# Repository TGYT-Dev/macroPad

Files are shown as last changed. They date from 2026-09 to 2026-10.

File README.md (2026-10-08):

# Images

<p align="left">
  MacroPad Foot
  MacroPad PCB<br>
  MacroPad Schem
  MacroPad Case / Assembly
</p>

# Bill of Materials
This should all be iuncluded in the macropad kit.

> 5x Cherry MX Switches
> 
> 1x Alps EC11E Rotary Encoder
> 
> 1x Seeeduino XIAO
> 
> 1x 0.91" 128x32 OLED Display
> 
> 4x M3 screws

# Notes

This is my first hardware project and I hope It turns out well... ~waiting for a review and working on minor improvements in the meantime.~

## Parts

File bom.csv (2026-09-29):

Id | Designator | Footprint | Quantity | Designation | Supplier and ref
1 | SW1, SW2, SW3, SW4, SW5 | SW_Cherry_MX_1.00u_PCB | 5 | SW_Push
2 | SW6 | RotaryEncoder_Alps_EC11E-Switch_Vertical_H20mm | 1 | RotaryEncoder_Switch
3 | U1 | XIAO-Generic-Hybrid-14P-2.54-21X17.8MM | 1 | MOUDLE-SEEEDUINO-XIAO
4 | U2 | SSD1306-0.91-OLED-4pin-128x32 | 1 | ER_OLEDM0.91_1x-I2C

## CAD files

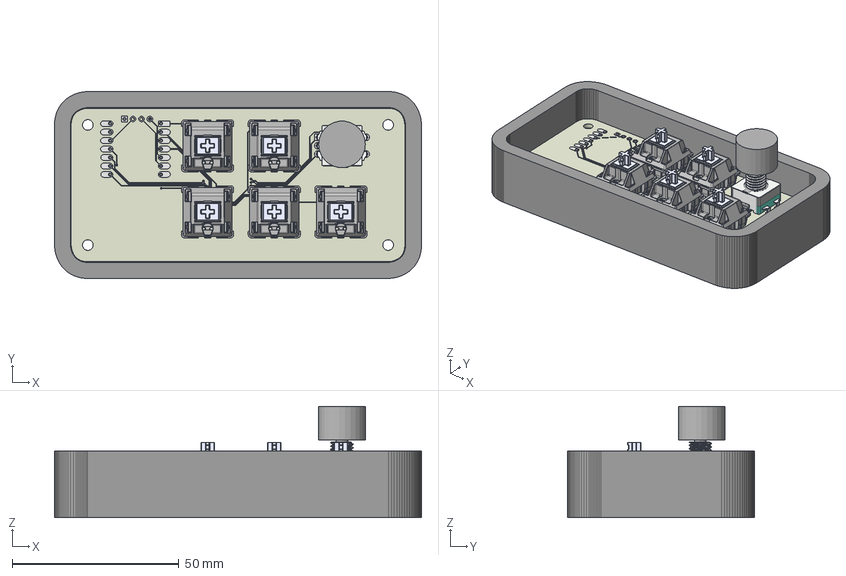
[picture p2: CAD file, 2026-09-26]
cad/MacroPad.step
110.0 x 56.0 x 33.3 mm
Case
Rotary Encoder Knob
BOSS-EXTRUDE14_6_
macroPad-unsaved-export-03wzKc_pad x 105
CUT-EXTRUDE5
Õë½Å___Ä¬ÈÏ__¨¨ _:1__Body1
macroPad-unsaved-export-03wzKc_copper x 26
Ñ½×ªÂ±áƒ«Ç· x 6
Õë½Å___Ä¬ÈÏ__¨¨ _:1__Body1_3
BOSS-EXTRUDE14_3_
U.FL Connector v1 x 3
macroPad-unsaved-export-03wzKc_PCB
BOSS-EXTRUDE7_2_
MX Ã–Ã¡ Â°Â´Â¼Ã¼ Â¡Ã¤_Â¨Â¹___Â¡Â§1:1__B ody1_4
MXÖá ÖáÌå µ×²¿ ¦Ì¡ Á2__Ä¬ÈÏ_¨¢2____¨¨_:1__Body1_3
Button (1)
macroPad-unsaved-export-03wzKc_via x 8
MX Ã–Ã¡ Â°Â´Â¼Ã¼ Â¡Ã¤_Â¨Â¹___Â¡Â§1:1__B ody1_3
MX Ã–Ã¡ Ã–Ã¡ÃŒÃ¥Â¨Â¢Â¨Â¬_ Â¡Â§Â¡Ã©Â¡Â§__:1__Body 1_4
BOSS-EXTRUDE7_6_
BOSS-EXTRUDE14_9_
Õë½Å___Ä¬ÈÏ__¨¨ _:1__Body2_4
MX Ã–Ã¡ Â°Â´Â¼Ã¼ Â¡Ã¤_Â¨Â¹___Â¡Â§1:1__B ody1
BOSS-EXTRUDE7_3_
BOSS-EXTRUDE14_7_
MX Ã–Ã¡ Ã–Ã¡ÃŒÃ¥Â¨Â¢Â¨Â¬_ Â¡Â§Â¡Ã©Â¡Â§__:1__Body 1_3
BOSS-EXTRUDE7_1_
Shield
Õë½Å___Ä¬ÈÏ__¨¨ _:1__Body2_3
BOSS-EXTRUDE14_8_
Button (1)_1
BOSS-EXTRUDE14_10_
Õë½Å___Ä¬ÈÏ__¨¨ _:1__Body2_1
Õë½Å___Ä¬ÈÏ__¨¨ _:1__Body2
Õë½Å___Ä¬ÈÏ__¨¨ _:1__Body1_2
MX Ã–Ã¡ Ã–Ã¡ÃŒÃ¥Â¨Â¢Â¨Â¬_ Â¡Â§Â¡Ã©Â¡Â§__:1__Body 1_1
MX Ã–Ã¡ Ã–Ã¡ÃŒÃ¥Â¨Â¢Â¨Â¬_ Â¡Â§Â¡Ã©Â¡Â§__:1__Body 1
BOSS-EXTRUDE14_4_
BOSS-EXTRUDE14_5_
BOSS-EXTRUDE14_11_
BOSS-EXTRUDE14_12_
BOSS-EXTRUDE7_8_
BOSS-EXTRUDE7_9_
BOSS-EXTRUDE14_2_
BOSS-EXTRUDE7_7_
MIRROR2
MX Ã–Ã¡ Â°Â´Â¼Ã¼ Â¡Ã¤_Â¨Â¹___Â¡Â§1:1__B ody1_2
MXÖá ÖáÌå µ×²¿ ¦Ì¡ Á2__Ä¬ÈÏ_¨¢2____¨¨_:1__Body1_2
Õë½Å___Ä¬ÈÏ__¨¨ _:1__Body1_1
Õë½Å___Ä¬ÈÏ__¨¨ _:1__Body1_4
MXÖá ÖáÌå µ×²¿ ¦Ì¡ Á2__Ä¬ÈÏ_¨¢2____¨¨_:1__Body1_1
BOSS-EXTRUDE7_5_
MXÖá ÖáÌå µ×²¿ ¦Ì¡ Á2__Ä¬ÈÏ_¨¢2____¨¨_:1__Body1
BOSS-EXTRUDE7_4_
BOSS-EXTRUDE14_1_
MX Ã–Ã¡ Ã–Ã¡ÃŒÃ¥Â¨Â¢Â¨Â¬_ Â¡Â§Â¡Ã©Â¡Â§__:1__Body 1_2
MX Ã–Ã¡ Â°Â´Â¼Ã¼ Â¡Ã¤_Â¨Â¹___Â¡Â§1:1__B ody1_1
Õë½Å___Ä¬ÈÏ__¨¨ _:1__Body2_2
MXÖá ÖáÌå µ×²¿ ¦Ì¡ Á2__Ä¬ÈÏ_¨¢2____¨¨_:1__Body1_4

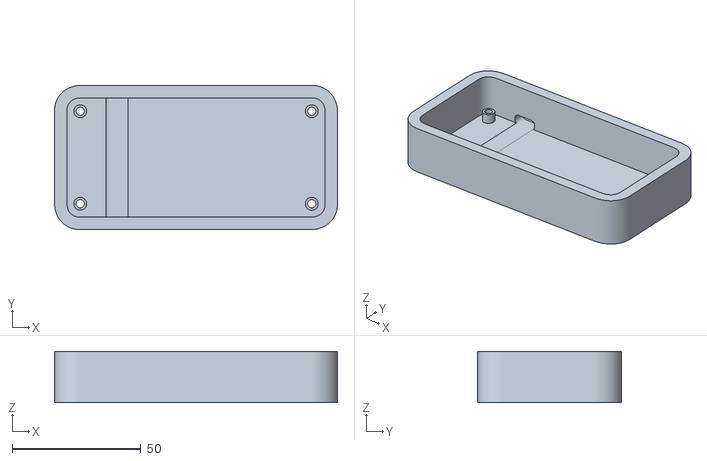
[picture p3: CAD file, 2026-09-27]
prod/case.stl
110.0 x 56.0 x 20.0

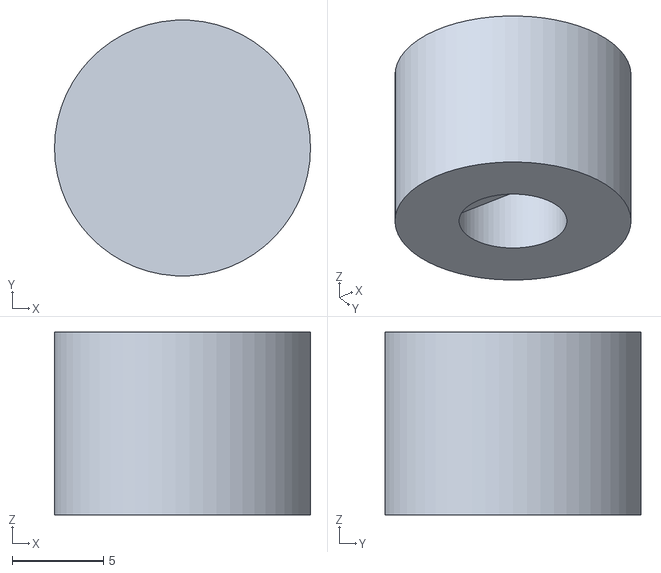
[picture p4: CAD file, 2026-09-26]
prod/rotaryEncoderKnob.stl
14.0 x 14.0 x 10.0

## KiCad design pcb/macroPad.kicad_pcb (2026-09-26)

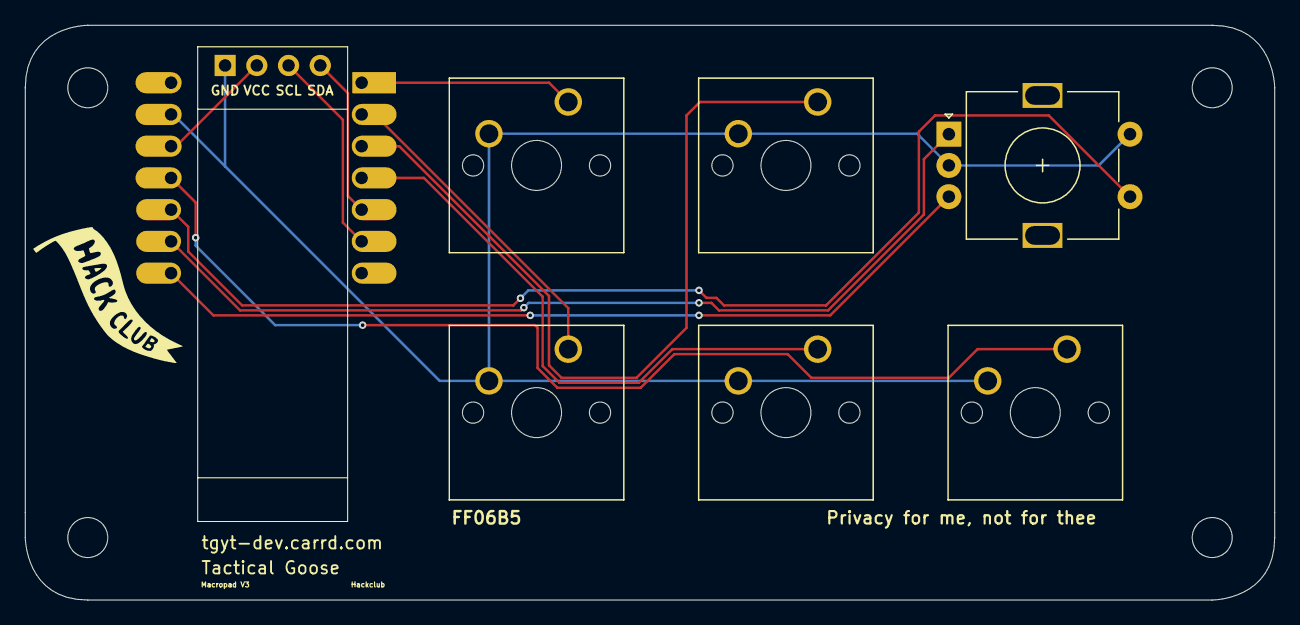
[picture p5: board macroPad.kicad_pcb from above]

Board: 2 copper layers, 100.0 x 46.0 mm, 12 parts (1 on the bottom side), 11 nets.

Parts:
H1, H2, H3, H4: MountingHole; MountingHole_3.2mm_M3
SW1, SW2, SW3, SW4, SW5: SW_Push; SW_Cherry_MX_1.00u_PCB
SW6: RotaryEncoder_Switch; RotaryEncoder_Alps_EC11E-Switch_Vertical_H20mm
U1: MOUDLE-SEEEDUINO-XIAO; XIAO-Generic-Hybrid-14P-2.54-21X17.8MM
U2: ER_OLEDM0.91_1x-I2C; SSD1306-0.91-OLED-4pin-128x32

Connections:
GND: SW1.2, SW2.2, SW3.2, SW4.2, SW5.2 (2_2), SW6.C, SW6.S2, U1.13 (GND), U2.1 (GND)
unnamed: U1.12 (3V3), U2.2 (VCC)
unnamed: SW1.1, U1.1 (PA02_A0_D0)
unnamed: SW2.1, U1.2 (PA4_A1_D1)
unnamed: SW6.S1, U1.10 (PA5_A9_D9_MISO)
unnamed: SW6.A, U1.9 (PA7_A8_D8_SCK)
unnamed: U1.5 (PA8_A4_D4_SDA), U2.4 (SDA)
unnamed: U1.6 (PA9_A5_D5_SCL), U2.3 (SCL)
unnamed: SW3.1, U1.3 (PA10_A2_D2)
unnamed: SW4.1, U1.4 (PA11_A3_D3)
unnamed: SW6.B, U1.8 (PB09_A7_D7_RX)

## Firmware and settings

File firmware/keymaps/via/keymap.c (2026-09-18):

#include QMK_KEYBOARD_H
#include "raw_hid.h"
#include <string.h>


const uint16_t PROGMEM keymaps[][MATRIX_ROWS][MATRIX_COLS] = {
    [0] = LAYOUT(
        KC_1, KC_2, KC_3, KC_4, KC_5, KC_MUTE
    )
};

#if defined(ENCODER_MAP_ENABLE)
const uint16_t PROGMEM encoder_map[][NUM_ENCODERS][NUM_DIRECTIONS] = {
    [0] = { ENCODER_CCW_CW(KC_VOLD, KC_VOLU) }
};
#endif

// --- Raw HID <-> OLED framebuffer bridge ---
// The companion app (written later) owns ALL rendering (text, icons, whatever).
// It rasterizes its own 128x32 monochrome image and sends the raw pixel bytes
// here; firmware just paints whatever bytes it's given. No font/icon logic
// lives in firmware at all.
//
// Frame size: 128 * 32 / 8 = 512 bytes total.
// HID packet payload: 31 usable bytes (byte 0 is a packet-index header).
// So a full frame = ceil(512 / 31) = 17 packets.
//
// Packet format:
//   byte 0      : packet index (0-16). Index 0xFF instead means "buffer ready,
//                 flip it to screen now" (an explicit "frame done" signal, so
//                 the companion app can send frames in any order/timing and
//                 firmware doesn't guess when a frame is complete).
//   bytes 1-31  : raw framebuffer bytes for this chunk (31 bytes/packet)

#define FB_SIZE 512
#define CHUNK_SIZE 31
#define TOTAL_CHUNKS 17  // ceil(512/31)
#define FRAME_DONE_MARKER 0xFF

static uint8_t framebuffer[FB_SIZE];
static bool frame_ready = false;

void raw_hid_receive_kb(uint8_t *data, uint8_t length) {
    if (length < 1) return;

    uint8_t cmd = data[0];

    if (cmd == FRAME_DONE_MARKER) {
        frame_ready = true;
        memset(data, 0, length);
        data[0] = 0x01; // ack: frame flipped
        return;
    }

    uint8_t index = cmd;
    // Support offset indexing (0x80 + index) to avoid VIA command ID collisions
    if (index >= 0x80 && index < 0x80 + TOTAL_CHUNKS) {
        index -= 0x80;
    }

    if (index >= TOTAL_CHUNKS) {
        data[0] = 0xFF; // unhandled
        return;
    }

    uint16_t offset = (uint16_t)index * CHUNK_SIZE;
    uint8_t copy_len = length - 1;
    if (offset + copy_len > FB_SIZE) {
        copy_len = FB_SIZE - offset; // clamp last chunk (512 isn't evenly divisible by 31)
    }
    memcpy(&framebuffer[offset], &data[1], copy_len);

    data[0] = 0x00; // ack: chunk received
}

#if defined(OLED_ENABLE)
bool oled_task_user(void) {
    if (frame_ready) {
        oled_write_raw((const char *)framebuffer, FB_SIZE);
        frame_ready = false;
    }
    return false;
}
#endif

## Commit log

2026-09-26 Adjusted Images and BOM Formating
2026-09-26 Rev
    Updated image sizes and corrected formatting in the Bill of Materials section.
2026-09-26 Replace w/ New Design
    [MacroPad.step]
2026-09-26 Replace w/ Updated Design
    [macroPad.kicad_pcb, macroPad.kicad_sch]
2026-09-26 removed leftover from old design
    [bottomShell.stl, topShell.stl]
2026-09-26 Prototyped a web maker for the OLED
2026-09-27 Fix case files
2026-09-27 Fix case files, again
    Case file was rotary enocoder knob
    [case.stl]
2026-09-27 Fix case file, for real this time
    [case.stl]
2026-09-29 Added BOM in .csv
    [macroPad.csv]
2026-10-03 Updated full assembly image
    TODO : Update STL and .Step
2026-10-08 Readded bom.csv
    [bom.csv]
